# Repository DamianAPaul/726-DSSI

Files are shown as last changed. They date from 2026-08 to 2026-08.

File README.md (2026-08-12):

# 726 Digital Sound Sequencing Instrument (726-DSSI)

A standalone digital synthesizer and 64-step sequencer designed around the Teensy 4.1.

The 726-DSSI is a personal embedded systems project combining real-time digital audio processing, custom C++ firmware, PCB design, physical controls, sequencing, and visual feedback.

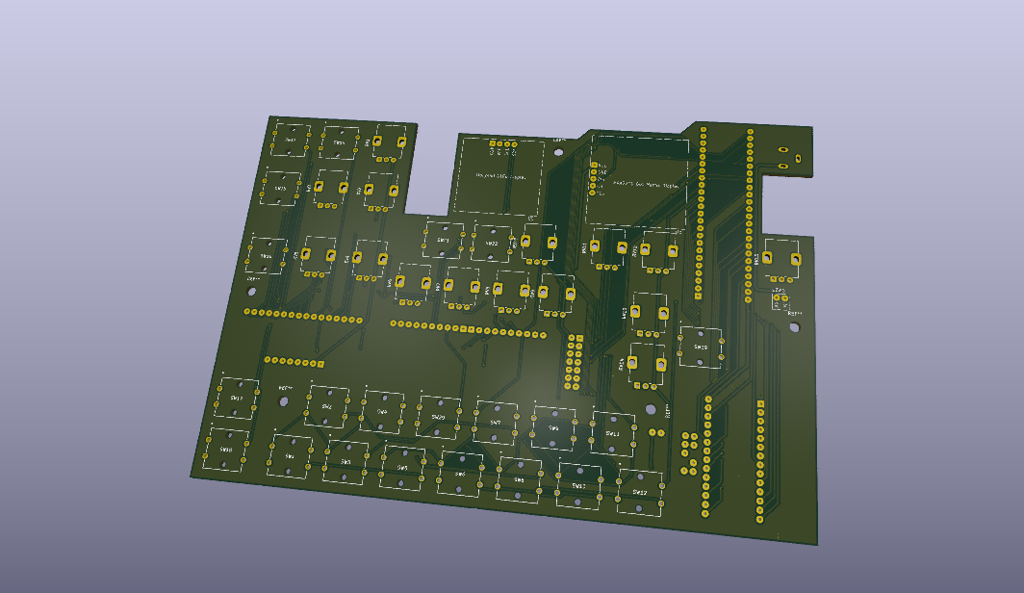
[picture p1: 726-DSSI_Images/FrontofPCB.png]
726-DSSI PCB 3D Front Render


## Features

- Up to 8 simultaneous oscillator, noise, or sample-based voices
- Per-voice filtering and amplitude envelopes
- 64-step sequencer
- Teensy 4.1 microcontroller
- PJRC Audio Shield
- SSD1306 OLED display
- MAX7219 8x8 LED matrix
- MCP23017 GPIO expansion
- CD74HC4067 analog multiplexing
- 3x4 keyboard matrix
- Custom C++ firmware using the Teensy Audio Library

## Hardware

I designed the schematic and PCB in KiCad, including custom schematic symbols and PCB footprints for several project-specific modules.

The first PCB revision has been fabricated, assembled, and validated; and is now awaiting shipping.

## Firmware

The firmware is written in C++ for the Teensy 4.1 using the Teensy Audio Library.

The firmware handles:

- Real-time audio synthesis and processing
- Voice management
- Sequencing
- Control scanning
- Analog multiplexing
- Keyboard input
- OLED and LED matrix feedback

## Repository Structure

- `726-DSSI_Firmware/` — Teensy C++ code, including the complete audio signal path
- `726-DSSI_CAD/` — KiCad schematic, PCB design files, custom footprint library, and gerbers
- `726-DSSI_Images/` — project images, mainly from prototyping phase

## Project Status

The breadboard prototype has been used for firmware and subsystem development. The first custom PCB revision has been fabricated, validated, and is awaiting shipping.

## Author

Damian Paul  
University of California, Berkeley  
Physics | Electrical Engineering & Computer Science

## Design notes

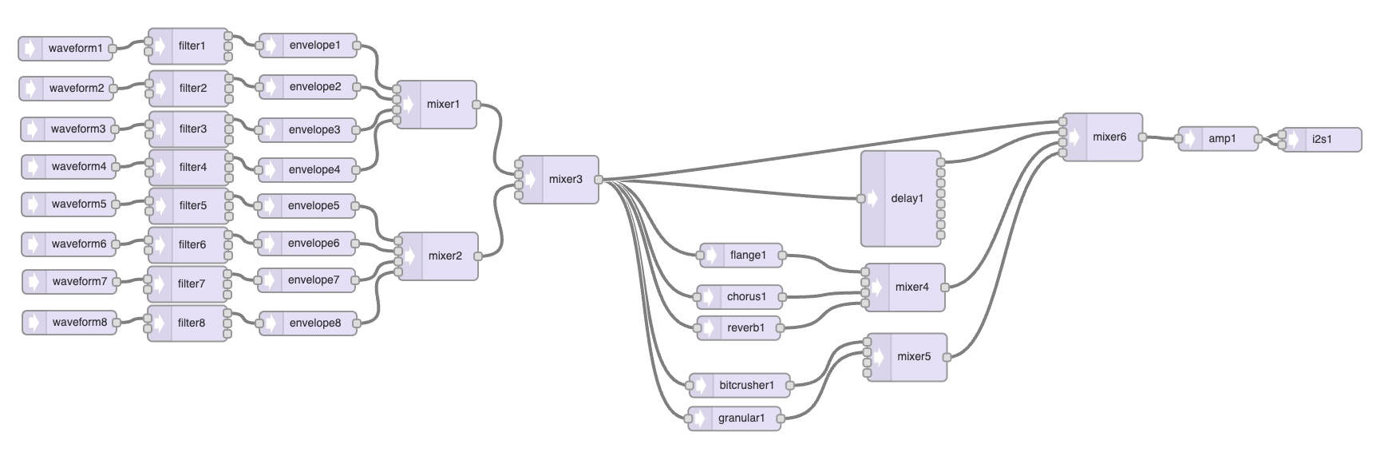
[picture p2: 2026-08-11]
726-DSSI_Images/Image 7-13-26 at 5.58 PM.jpg

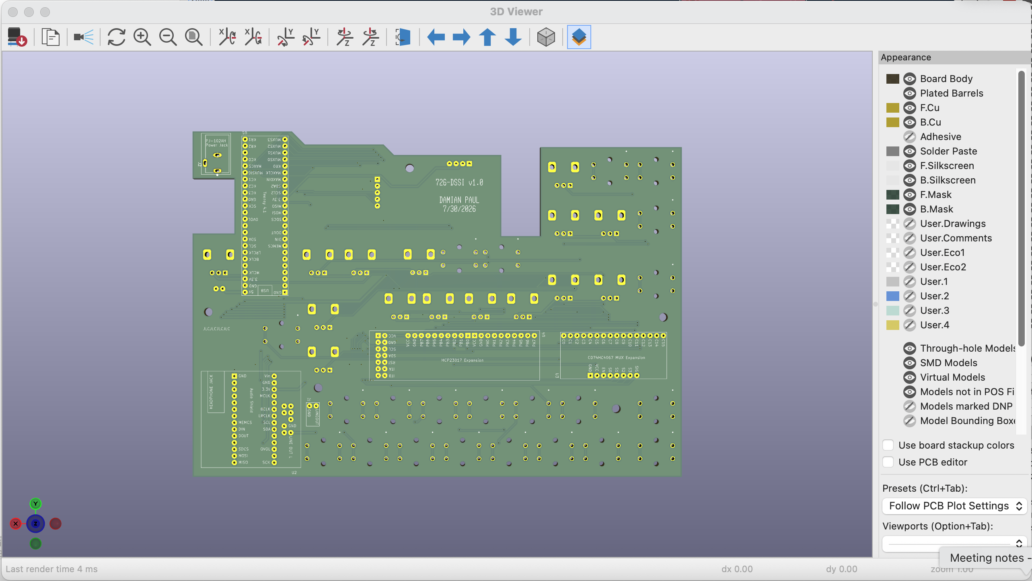
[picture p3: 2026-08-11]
726-DSSI_Images/Screenshot 2026-07-30 at 5.10.15 PM.png

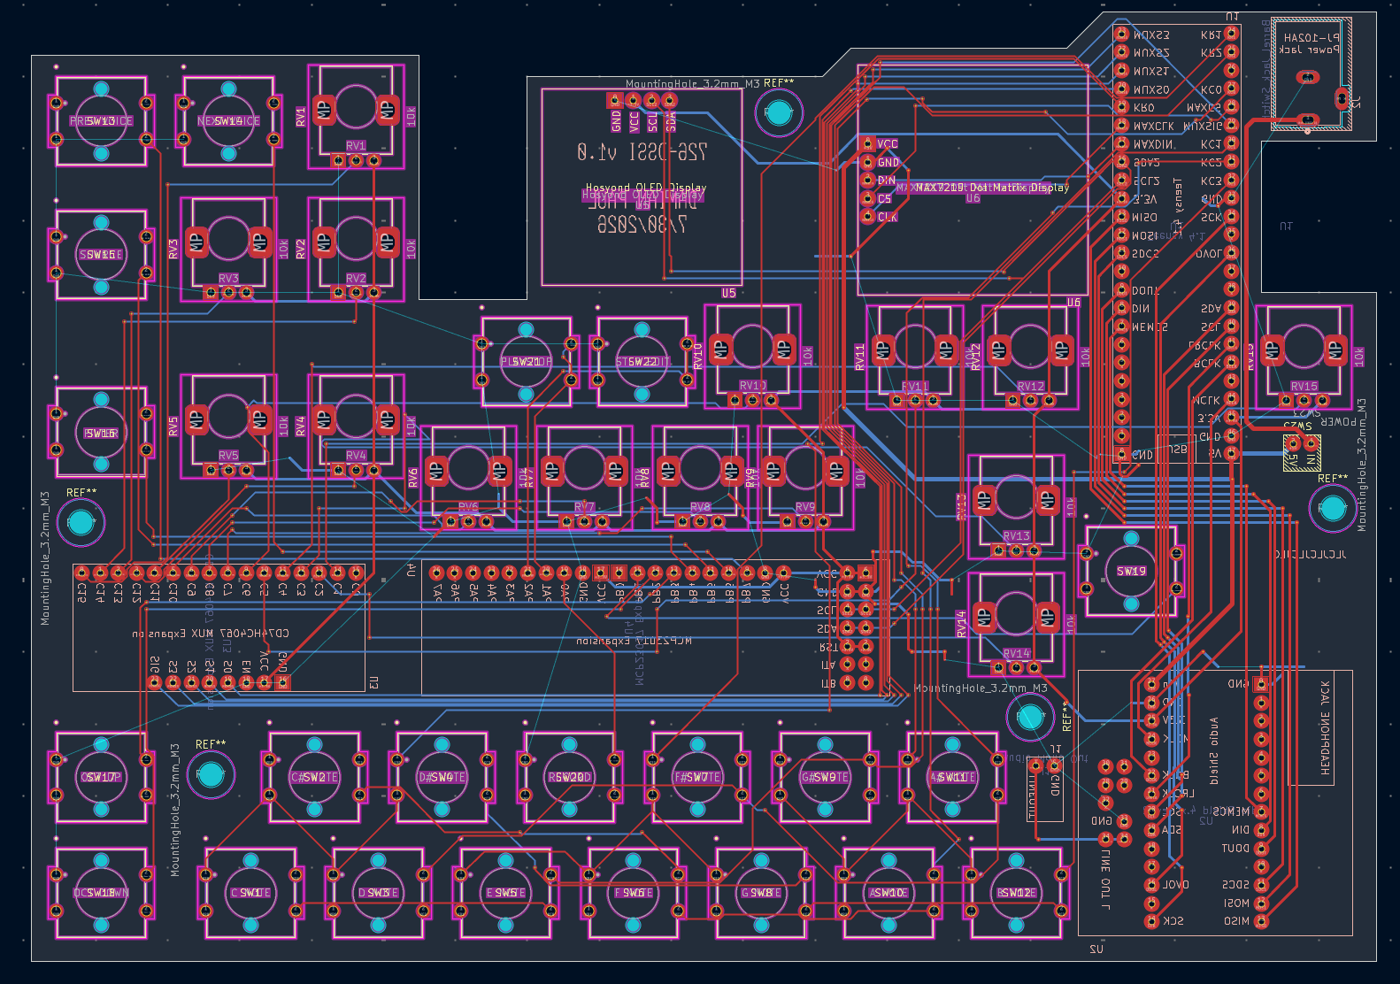
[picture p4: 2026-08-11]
726-DSSI_Images/Screenshot 2026-08-05 at 1.27.51 PM.png

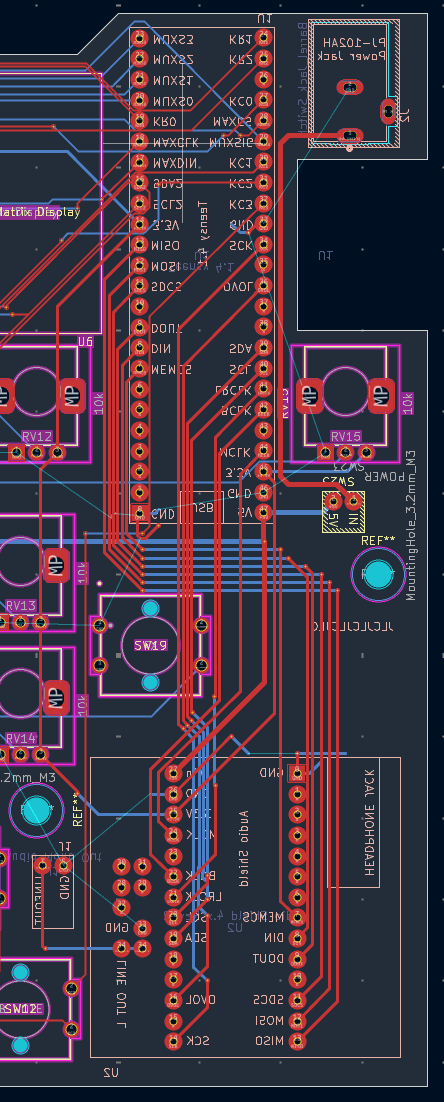
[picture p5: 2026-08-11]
726-DSSI_Images/Screenshot 2026-08-05 at 1.28.34 PM.png

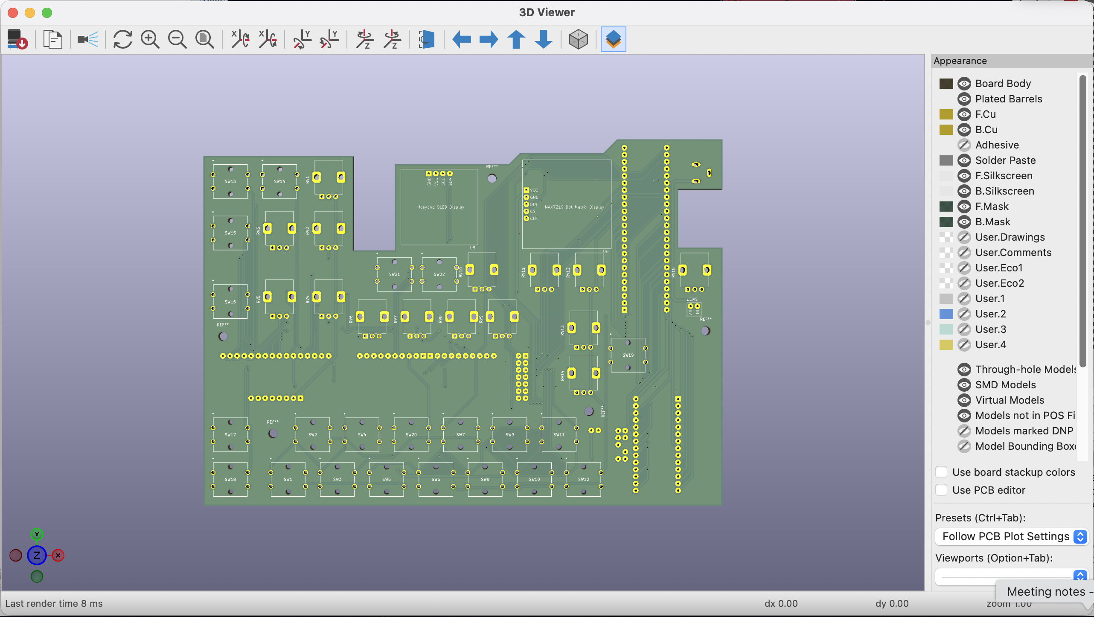
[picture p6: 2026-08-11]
726-DSSI_Images/Screenshot 2026-07-30 at 5.08.04 PM.png

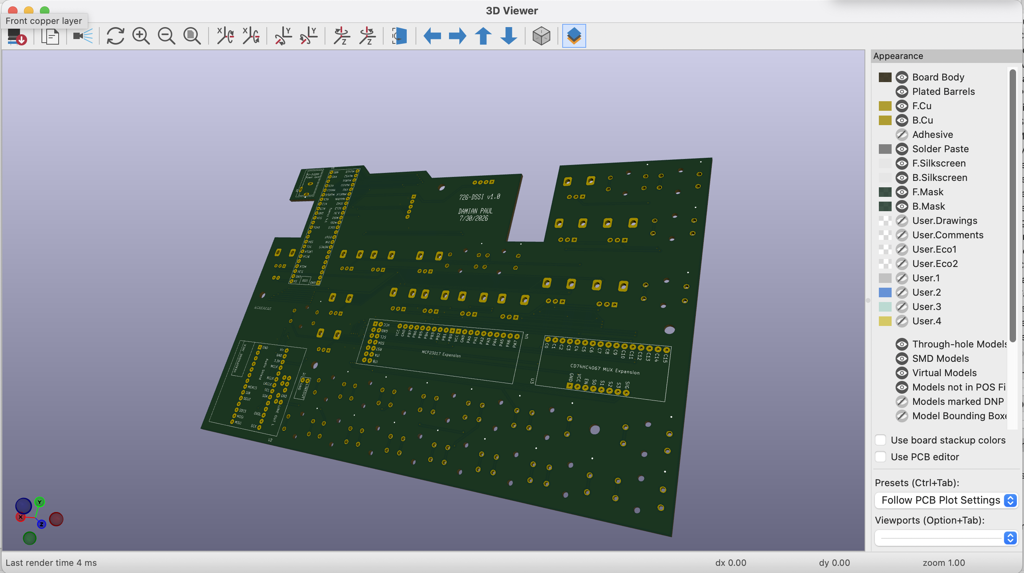
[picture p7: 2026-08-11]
726-DSSI_Images/Screenshot 2026-07-30 at 5.11.36 PM.png

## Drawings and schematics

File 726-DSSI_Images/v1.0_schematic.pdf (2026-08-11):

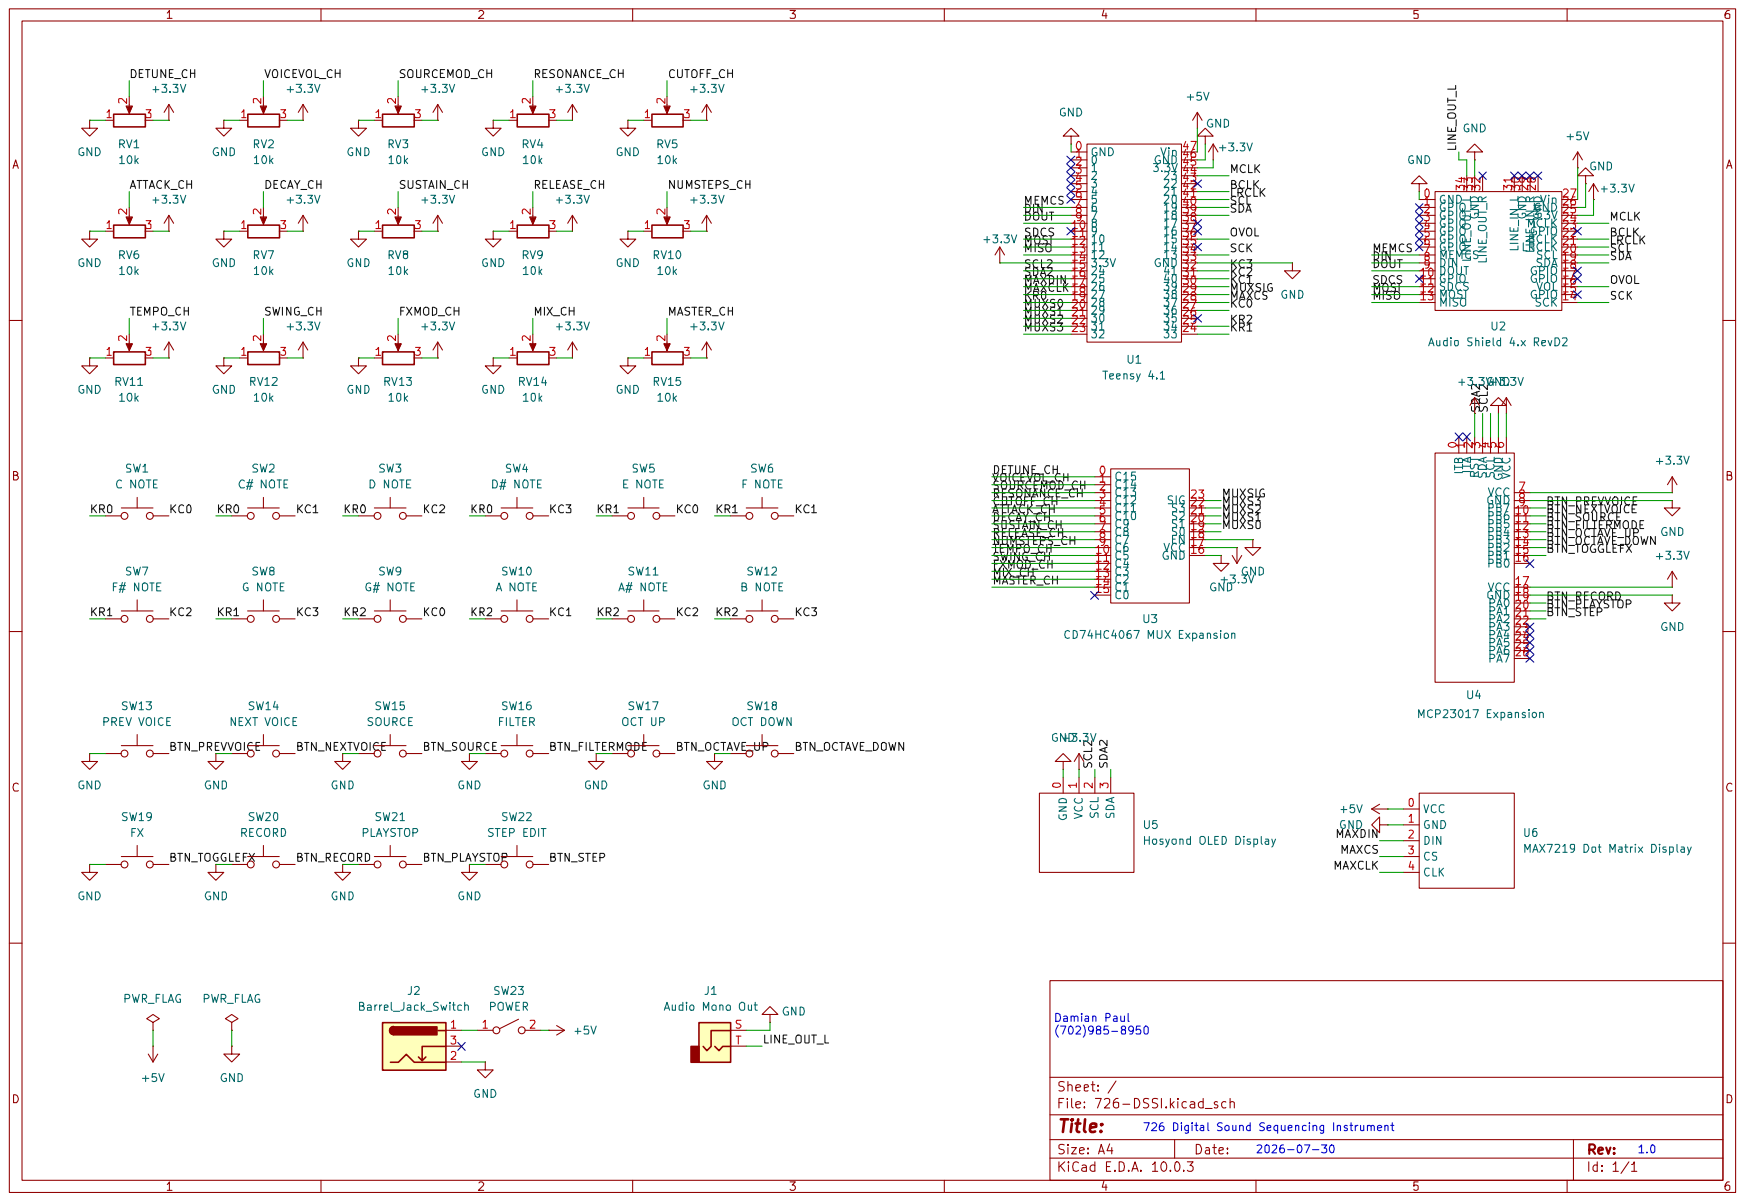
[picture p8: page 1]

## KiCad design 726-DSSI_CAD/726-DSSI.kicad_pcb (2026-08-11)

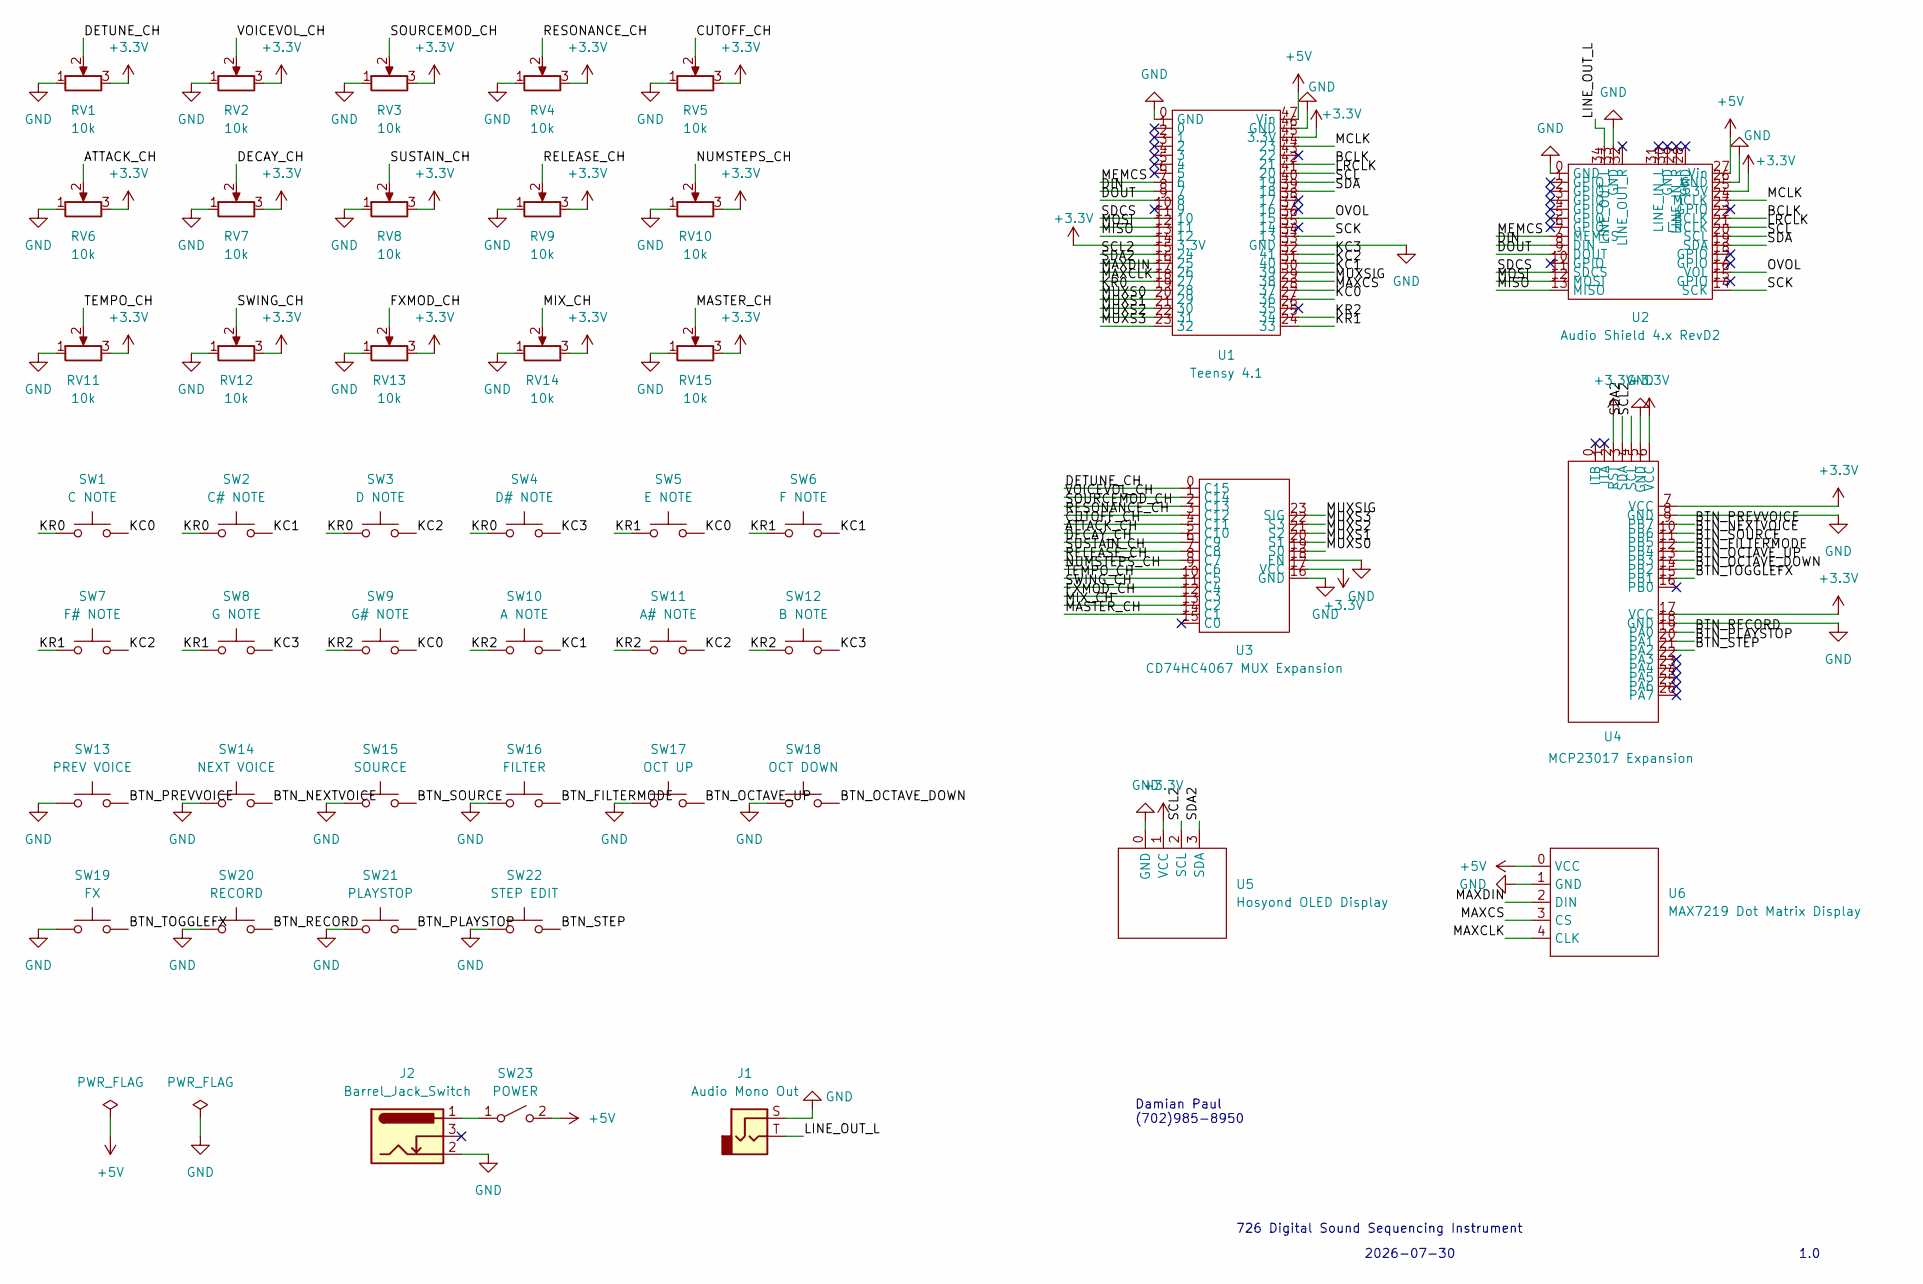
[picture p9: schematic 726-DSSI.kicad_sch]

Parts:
J1: Audio Mono Out; AudioJackOutMono
J2: Barrel_Jack_Switch; PJ102AH Power Jack
RV1, RV2, RV3, RV4, RV5, RV6, RV7, RV8, RV9, RV10, RV11, RV12, RV13, RV14, RV15: 10k; Potentiometer_Alps_RK09K_Single_Vertical
SW1: C NOTE; B3F-4050_ButtonSwitch
SW2: C# NOTE; B3F-4050_ButtonSwitch
SW3: D NOTE; B3F-4050_ButtonSwitch
SW4: D# NOTE; B3F-4050_ButtonSwitch
SW5: E NOTE; B3F-4050_ButtonSwitch
SW6: F NOTE; B3F-4050_ButtonSwitch
SW7: F# NOTE; B3F-4050_ButtonSwitch
SW8: G NOTE; B3F-4050_ButtonSwitch
SW9: G# NOTE; B3F-4050_ButtonSwitch
SW10: A NOTE; B3F-4050_ButtonSwitch
SW11: A# NOTE; B3F-4050_ButtonSwitch
SW12: B NOTE; B3F-4050_ButtonSwitch
SW13: PREV VOICE; B3F-4050_ButtonSwitch
SW14: NEXT VOICE; B3F-4050_ButtonSwitch
SW15: SOURCE; B3F-4050_ButtonSwitch
SW16: FILTER; B3F-4050_ButtonSwitch
SW17: OCT UP; B3F-4050_ButtonSwitch
SW18: OCT DOWN; B3F-4050_ButtonSwitch
SW19: FX; B3F-4050_ButtonSwitch
SW20: RECORD; B3F-4050_ButtonSwitch
SW21: PLAYSTOP; B3F-4050_ButtonSwitch
SW22: STEP EDIT; B3F-4050_ButtonSwitch
SW23: POWER; SW-T3-1A-A-A3-S1 ToggleSwitchPower
U1: Teensy 4.1
U2: Audio Shield 4.x RevD2; Teensy Audio Shield RevD
U3: CD74HC4067 MUX Expansion
U4: MCP23017 Expansion
U5: Hosyond OLED Display
U6: MAX7219 Dot Matrix Display

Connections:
+3.3V: RV1.3, RV2.3, RV3.3, RV4.3, RV5.3, RV6.3, RV7.3, RV8.3, RV9.3, RV10.3, RV11.3, RV12.3, RV13.3, RV14.3, RV15.3, U1.14 (3.3V), U1.45 (3.3V), U2.25 (3.3V), U3.17 (VCC), U4.2 (RST), U4.6 (VCC), U4.7 (VCC), U4.17 (VCC), U5.1 (VCC)
+5V: SW23.2 (B), U1.47 (Vin), U2.27 (Vin), U6.0 (VCC)
/ATTACK_CH: RV6.2, U3.5 (C10)
/BCLK: U1.42 (21), U2.22 (BCLK)
/BTN_FILTERMODE: SW16.2, U4.12 (PB4)
/BTN_NEXTVOICE: SW14.2, U4.10 (PB6)
/BTN_OCTAVE_DOWN: SW18.2, U4.14 (PB2)
/BTN_OCTAVE_UP: SW17.2, U4.13 (PB3)
/BTN_PLAYSTOP: SW21.2, U4.20 (PA1)
/BTN_PREVVOICE: SW13.2, U4.9 (PB7)
/BTN_RECORD: SW20.2, U4.19 (PA0)
/BTN_SOURCE: SW15.2, U4.11 (PB5)
/BTN_STEP: SW22.2, U4.21 (PA2)
/BTN_TOGGLEFX: SW19.2, U4.15 (PB1)
/CUTOFF_CH: RV5.2, U3.4 (C11)
/DECAY_CH: RV7.2, U3.6 (C9)
/DETUNE_CH: RV1.2, U3.0 (C15)
/DIN: U1.8 (7), U2.8 (DIN)
/DOUT: U1.9 (8), U2.9 (DOUT)
/FXMOD_CH: RV13.2, U3.12 (C3)
/KC0: SW1.2, SW5.2, SW9.2, U1.27 (36)
/KC1: SW2.2, SW6.2, SW10.2, U1.30 (39)
/KC2: SW3.2, SW7.2, SW11.2, U1.31 (40)
/KC3: SW4.2, SW8.2, SW12.2, U1.32 (41)
/KR0: SW1.1, SW2.1, SW3.1, SW4.1, U1.19 (28)
/KR1: SW5.1, SW6.1, SW7.1, SW8.1, U1.24 (33)
/KR2: SW9.1, SW10.1, SW11.1, SW12.1, U1.25 (34)
/LINE_OUT_L: J1.T, U2.34 (LINE_OUT_L)
/LRCLK: U1.41 (20), U2.21 (LRCLK)
/MASTER_CH: RV15.2, U3.14 (C1)
/MAXCLK: U1.18 (27), U6.4 (CLK)
/MAXCS: U1.28 (37), U6.3 (CS)
/MAXDIN: U1.17 (26), U6.2 (DIN)
/MCLK: U1.44 (23), U2.24 (MCLK)
/MEMCS: U1.7 (6), U2.7 (MEMCS)
/MISO: U1.13 (12), U2.13 (MISO)
/MIX_CH: RV14.2, U3.13 (C2)
/MOSI: U1.12 (11), U2.12 (MOSI)
/MUXS0: U1.20 (29), U3.19 (S0)
/MUXS1: U1.21 (30), U3.20 (S1)
/MUXS2: U1.22 (31), U3.21 (S2)
/MUXS3: U1.23 (32), U3.22 (S3)
/MUXSIG: U1.29 (38), U3.23 (SIG)
/NUMSTEPS_CH: RV10.2, U3.9 (C6)
/OVOL: U1.36 (15), U2.16 (VOL)
/RELEASE_CH: RV9.2, U3.8 (C7)
/RESONANCE_CH: RV4.2, U3.3 (C12)
/SCK: U1.34 (13), U2.14 (SCK)
/SCL: U1.40 (19), U2.20 (SCL)
/SCL2: U1.15 (24), U4.4 (SCL), U5.2 (SCL)
/SDA: U1.39 (18), U2.19 (SDA)
/SDA2: U1.16 (25), U4.3 (SDA), U5.3 (SDA)
/SDCS: U1.11 (10), U2.11 (SDCS)
/SOURCEMOD_CH: RV3.2, U3.2 (C13)
/SUSTAIN_CH: RV8.2, U3.7 (C8)
/SWING_CH: RV12.2, U3.11 (C4)
/TEMPO_CH: RV11.2, U3.10 (C5)
/VOICEVOL_CH: RV2.2, U3.1 (C14)
GND: J1.S, J2.2, RV1.1, RV2.1, RV3.1, RV4.1, RV5.1, RV6.1, RV7.1, RV8.1, RV9.1, RV10.1, RV11.1, RV12.1, RV13.1, RV14.1, RV15.1, SW13.1, SW14.1, SW15.1, SW16.1, SW17.1, SW18.1, SW19.1, SW20.1, SW21.1, SW22.1, U1.0 (GND), U1.33 (GND), U1.46 (GND), U2.0 (GND), U2.26 (GND), U2.33 (GND), U3.16 (GND), U3.18 (EN), U4.5 (GND), U4.8 (GND), U4.18 (GND), U5.0 (GND), U6.1 (GND)
unnamed: J2.1, SW23.1 (A)

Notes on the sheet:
726 Digital Sound Sequencing Instrument
1.0
Damian Paul (702)985-8950
2026-07-30

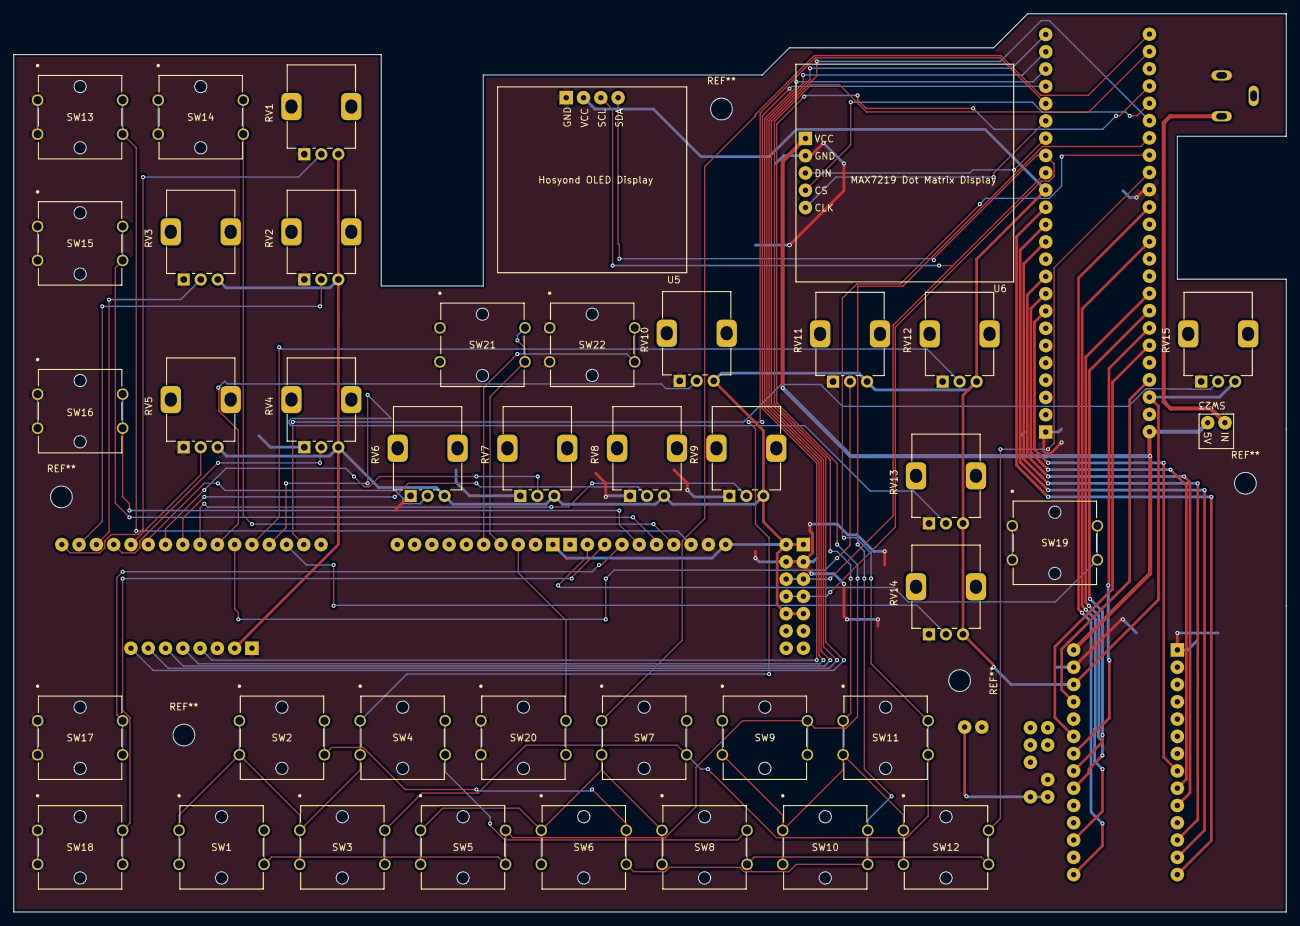
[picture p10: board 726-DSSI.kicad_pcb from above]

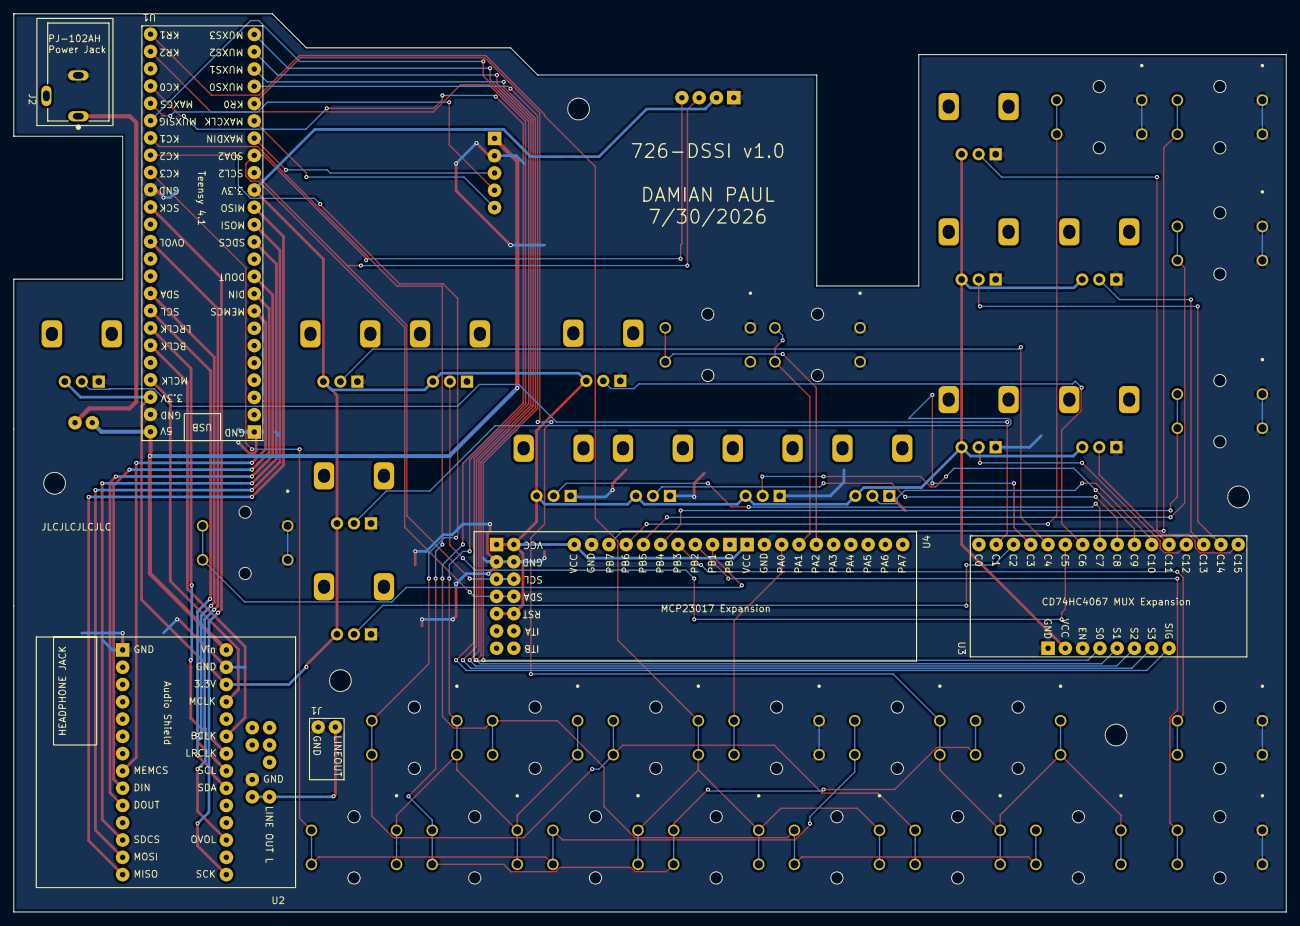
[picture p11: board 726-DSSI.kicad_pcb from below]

Board: 2 copper layers, 187.0 x 132.0 mm, 46 parts (6 on the bottom side), 60 nets.

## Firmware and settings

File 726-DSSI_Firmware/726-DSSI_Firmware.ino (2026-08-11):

#include "AudioObjects.h"
#include "AudioSystem.h"
#include "Controls.h"
#include "AudioSystem.h"
#include "Voice.h"
#include "Display.h"
#include "Keyboard.h"
#include "Sequencer.h"

void setup()
{
    Serial.begin(115200);
    while (!Serial && millis() < 3000);
    Serial.println("Starting Synth...");

    Voices.begin();
    initAudio();

    Controls::begin();
    OLED.begin();
    Keyboard::begin();
    Sequencer::begin();
}

void loop()
{
    Controls::update();
    OLED.update();
    Keyboard::update();
    Keyboard::update();
    Sequencer::update();
}

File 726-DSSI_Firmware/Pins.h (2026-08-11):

#pragma once

#include <Arduino.h>

// ---------- I2C ----------
constexpr uint8_t I2C_SCL = 24;
constexpr uint8_t I2C_SDA = 25;

// ---------- Perform ----------
// Rows (outputs)
constexpr uint8_t KEY_ROW0 = 28;
constexpr uint8_t KEY_ROW1 = 33;
constexpr uint8_t KEY_ROW2 = 34;

// Columns (inputs)
constexpr uint8_t KEY_COL0 = 36;
constexpr uint8_t KEY_COL1 = 39;
constexpr uint8_t KEY_COL2 = 40;
constexpr uint8_t KEY_COL3 = 41;



// ---------- Multiplexer ----------

constexpr uint8_t MUX_S0 = 29;
constexpr uint8_t MUX_S1 = 30;
constexpr uint8_t MUX_S2 = 31;
constexpr uint8_t MUX_S3 = 32;

constexpr uint8_t MUX_SIG = A14;

// Multiplexer channels

constexpr uint8_t DETUNE_CH       = 15;
constexpr uint8_t VOICEVOL_CH     = 14;
constexpr uint8_t SOURCEMOD_CH    = 13;
constexpr uint8_t RESONANCE_CH    = 12;
constexpr uint8_t CUTOFF_CH       = 11;
constexpr uint8_t ATTACK_CH       = 10;
constexpr uint8_t DECAY_CH        = 9;
constexpr uint8_t SUSTAIN_CH      = 8;
constexpr uint8_t RELEASE_CH      = 7;
constexpr uint8_t NUMSTEPS_CH     = 6;
constexpr uint8_t TEMPO_CH        = 5;
constexpr uint8_t SWING_CH        = 4;
constexpr uint8_t FXMOD_CH        = 3;
constexpr uint8_t MIX_CH          = 2;
constexpr uint8_t MASTER_CH       = 1;

// ---------- MCP ----------

constexpr uint8_t MCP_ADDR = 0x20;

// Port A
constexpr uint8_t BTN_RECORD       = 0; // PA0
constexpr uint8_t BTN_PLAYSTOP     = 1; // PA1
constexpr uint8_t BTN_STEP         = 2; // PA2

// Port B
constexpr uint8_t BTN_TOGGLEFX    = 9;  // PB1
constexpr uint8_t BTN_OCTAVE_DOWN  = 10; // PB2;
constexpr uint8_t BTN_OCTAVE_UP    = 11; // PB3;
constexpr uint8_t BTN_FILTERMODE   = 12; // PB4
constexpr uint8_t BTN_SOURCE       = 13; // PB5
constexpr uint8_t BTN_NEXTVOICE    = 14; // PB6
constexpr uint8_t BTN_PREVVOICE    = 15; // PB7

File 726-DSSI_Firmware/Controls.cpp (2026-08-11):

#include "Controls.h"
#include "Pins.h"
#include "Voice.h"
#include "AudioSystem.h"
#include "FX.h"
#include "Keyboard.h"
#include "Sequencer.h"
#include "Display.h"

#include <Wire.h>

#include <Adafruit_MCP23X17.h>
Adafruit_MCP23X17 mcp;


static bool lastOctUp = false;
static bool lastOctDown = false;
static uint32_t lastOctaveTime = 0;
const uint32_t OCTAVE_DEBOUNCE_MS = 150;
const int KNOB_CHANGE_THRESHOLD = 3;
const int KNOB_SMOOTHING_SHIFT = 2;
const int MUX_READ_SAMPLES = 8;
const int STEPPED_CONTROL_HYSTERESIS = 8;

// ---------------- MUX ----------------

int lastKnobValues[16];
int smoothedKnobValues[16];

static int stableMappedValue(int rawValue,
                             int currentValue,
                             int outMin,
                             int outMax)
{
    int candidate = map(rawValue, 0, 1023, outMin, outMax);

    if(currentValue < 0 || candidate == currentValue)
        return candidate;

    long center =
        (long)(currentValue - outMin) * 1023L /
        (long)(outMax - outMin);

    if(abs(rawValue - center) >= STEPPED_CONTROL_HYSTERESIS)
        return candidate;

    return currentValue;
}

static String percentValue(int value)
{
    return String(map(value, 0, 1023, 0, 100)) + "%";
}

static String cutoffValue(int value)
{
    return String(map(value, 0, 1023, 40, 12000)) + " Hz";
}

static String resonanceValue(int value)
{
    int qTimes100 = map(value, 0, 1023, 70, 500);

    return String(qTimes100 / 100) + "." +
           String((qTimes100 / 10) % 10) +
           String(qTimes100 % 10) + " Q";
}

static String attackValue(int value)
{
    return String(map(value, 0, 1023, 0, 2000)) + " ms";
}

static String decayValue(int value)
{
    return String(map(value, 0, 1023, 0, 3000)) + " ms";
}

static String releaseValue(int value)
{
    return String(map(value, 0, 1023, 0, 4000)) + " ms";
}

static String detuneValue(int value)
{
    return String(map(value, 0, 1023, -500, 500) / 10.0f, 1) + "%";
}

void selectMuxChannel(uint8_t channel)
{
    digitalWrite(MUX_S0, channel & 0x01);
    digitalWrite(MUX_S1, (channel >> 1) & 0x01);
    digitalWrite(MUX_S2, (channel >> 2) & 0x01);
    digitalWrite(MUX_S3, (channel >> 3) & 0x01);

    delayMicroseconds(5);
}

int readMux(uint8_t channel)
{
    selectMuxChannel(channel);

    analogRead(MUX_SIG);

    int total = 0;

    for(int i = 0; i < MUX_READ_SAMPLES; i++)
        total += analogRead(MUX_SIG);

    return total / MUX_READ_SAMPLES;
}

void Controls::begin()
{
    // ---------- I2C ----------
    Wire2.begin();

    Serial.println("Initializing MCP...");
    bool found = false;
    for (int i = 0; i < 10; i++)
    {
        if (mcp.begin_I2C(MCP_ADDR, &Wire2))
        {
            found = true;
            break;
        }

        delay(10);
    }
    if (!found)
    {
        Serial.println("FAILED");
        while (1);
    }
    Serial.println("SUCCESS");


    // ---------- Multiplexer ----------

    pinMode(MUX_S0, OUTPUT);
    pinMode(MUX_S1, OUTPUT);
    pinMode(MUX_S2, OUTPUT);
    pinMode(MUX_S3, OUTPUT);

    pinMode(MUX_SIG, INPUT);

    // ---------- MCP Buttons ----------

    mcp.pinMode(BTN_FILTERMODE, INPUT_PULLUP);
    mcp.pinMode(BTN_SOURCE, INPUT_PULLUP);
    mcp.pinMode(BTN_NEXTVOICE, INPUT_PULLUP);
    mcp.pinMode(BTN_PREVVOICE, INPUT_PULLUP);
    mcp.pinMode(BTN_OCTAVE_UP, INPUT_PULLUP);
    mcp.pinMode(BTN_OCTAVE_DOWN, INPUT_PULLUP);
    mcp.pinMode(BTN_RECORD, INPUT_PULLUP);
    mcp.pinMode(BTN_PLAYSTOP, INPUT_PULLUP);
    mcp.pinMode(BTN_STEP, INPUT_PULLUP);
    mcp.pinMode(BTN_TOGGLEFX, INPUT_PULLUP);

    Serial.print("GPIOA = ");
    Serial.println(mcp.readGPIOA(), BIN);

    Serial.print("GPIOB = ");
    Serial.println(mcp.readGPIOB(), BIN);

    // ---------- Initialize knob history ----------

    for (int i = 0; i < 16; i++)
    {
        lastKnobValues[i] = -1;
        smoothedKnobValues[i] = -1;
    }

    Serial.println("Controls initialized.");
}


void Controls::update()
{
    const uint8_t channels[] =
    {
        DETUNE_CH,
        VOICEVOL_CH,
        SOURCEMOD_CH,
        RESONANCE_CH,
        CUTOFF_CH,
        ATTACK_CH,
        DECAY_CH,
        SUSTAIN_CH,
        RELEASE_CH,
        TEMPO_CH,
        NUMSTEPS_CH,
        FXMOD_CH,
        MIX_CH,
        MASTER_CH
    };

    for(size_t i = 0; i < sizeof(channels)/sizeof(channels[0]); i++)
    {
        int rawValue = readMux(channels[i]);
        uint8_t channel = channels[i];

        if(smoothedKnobValues[channel] < 0)
            smoothedKnobValues[channel] = rawValue;
        else
            smoothedKnobValues[channel] =
                ((smoothedKnobValues[channel] *
                  ((1 << KNOB_SMOOTHING_SHIFT) - 1)) +
                 rawValue) >>
                KNOB_SMOOTHING_SHIFT;

        int value = smoothedKnobValues[channel];

        if(abs(value-lastKnobValues[channel]) >= KNOB_CHANGE_THRESHOLD)
        {
            lastKnobValues[channel]=value;

            switch(channels[i])
            {
                case DETUNE_CH:
                    Voices.setDetune(value);
                    updateVoice(Voices.getCurrentVoice());

                    OLED.showPopup(
                        "Detune",
                        detuneValue(value)
                    );
                    break;

                case VOICEVOL_CH:
                    Voices.setVolume(value);
                    updateVoice(Voices.getCurrentVoice());

                    OLED.showPopup(
                        "Volume",
                        percentValue(value)
                    );
                    break;

                case SOURCEMOD_CH:
                    Voices.setSourceMod(value);
                    updateVoice(Voices.getCurrentVoice());

                    OLED.showPopup(
                        "Mod",
                        percentValue(value)
                    );
                    break;

                case CUTOFF_CH:
                    Voices.setCutoff(value);
                    updateVoice(Voices.getCurrentVoice());

                    OLED.showPopup(
                        "Cutoff",
                        cutoffValue(value)
                    );
                    break;

                case RESONANCE_CH:
                    Voices.setResonance(value);
                    updateVoice(Voices.getCurrentVoice());

                    OLED.showPopup(
                        "Resonance",
                        resonanceValue(value)
                    );
                    break;

                case ATTACK_CH:
                    Voices.setAttack(value);
                    updateVoice(Voices.getCurrentVoice());

                    OLED.showPopup(
                        "Attack",
                        attackValue(value)
                    );
                    break;

                case DECAY_CH:
                    Voices.setDecay(value);
                    updateVoice(Voices.getCurrentVoice());
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

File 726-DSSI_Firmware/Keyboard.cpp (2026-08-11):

#include "Keyboard.h"
#include "Pins.h"
#include "AudioSystem.h"
#include "Voice.h"


int octaveOffset = 0;


const uint8_t rowPins[3] =
{
    KEY_ROW0,
    KEY_ROW1,
    KEY_ROW2
};

const uint8_t colPins[4] =
{
    KEY_COL0,
    KEY_COL1,
    KEY_COL2,
    KEY_COL3
};

// MIDI notes, instead of frequencies
const uint8_t keyNotes[3][4] =
{
    {60,61,62,63},
    {64,65,66,67},
    {68,69,70,71}
};


bool keyState[3][4] = { false };

int activeRow = -1;
int activeCol = -1;


bool notePressedFlag = false;
bool noteReleasedFlag = false;
uint8_t lastMidiNote = 60;



void Keyboard::begin()
{
    for(int r=0;r<3;r++)
    {
        pinMode(rowPins[r],OUTPUT);

        digitalWrite(rowPins[r],HIGH);
    }

    for(int c=0;c<4;c++)
    {
        pinMode(
            colPins[c],
            INPUT_PULLUP
        );
    }
}

void Keyboard::update()
{
    for(int r=0;r<3;r++)
    {
        for(int i=0;i<3;i++)
            digitalWrite(rowPins[i],HIGH);

        digitalWrite(rowPins[r],LOW);

        delayMicroseconds(5);

        for(int c=0;c<4;c++)
        {
            bool pressed =
                digitalRead(colPins[c]) == LOW;

            if(
                pressed &&
                !keyState[r][c]
            )
            {
                keyState[r][c] = true;

                uint8_t note =
                    keyNotes[r][c]
                    +
                    octaveOffset*12;

                activeRow = r;
                activeCol = c;

                lastMidiNote = note;
                notePressedFlag = true;
            }

            if(
                !pressed &&
                keyState[r][c]
            )
            {
                keyState[r][c] = false;

                if(activeRow == r &&
                    activeCol == c)
                    {
                        activeRow = -1;
                        activeCol = -1;

                        noteReleasedFlag = true;
                    }
            }
        }
    }
}


void Keyboard::octaveUp()
{
    if(octaveOffset < 3)
        octaveOffset++;
    Serial.print("Octave = ");
    Serial.println(octaveOffset);
}

void Keyboard::octaveDown()
{
    if(octaveOffset > -3)
        octaveOffset--;
    Serial.print("Octave = ");
    Serial.println(octaveOffset);
}


bool Keyboard::notePressed()
{
    bool result = notePressedFlag;
    notePressedFlag = false;
    return result;
}

bool Keyboard::noteReleased()
{
    bool result = noteReleasedFlag;
    noteReleasedFlag = false;
    return result;
}

uint8_t Keyboard::getPressedMidiNote()
{
    return lastMidiNote;
}

int Keyboard::getOctave()
{
    return octaveOffset;
}
